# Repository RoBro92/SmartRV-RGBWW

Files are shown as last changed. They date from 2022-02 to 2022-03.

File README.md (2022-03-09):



# SmartRV RGBWW Controller
**A ESP32 based RGBWW controller**

All feature requests are tracked in the GitHub issue tracker. 
[Feature Requests](https://github.com/RoBro92/feature-requests/issues)

This RGBWW control board has been designed to allow smart control of an attached LED strip. It supports 5 seperate channels that are switched via N Channel Mosfets, this is sutiable for the majority of LV LED devices. It is designed to integrate with a home automation system such as Home Assistant, though can operate standalone via an access point.

The module has been kept as compact as possible and allows for a direct connection to 12v or 24v vehicle systems. 

**If you want to support the development you can purchase this board as a DIY kit or assembled from my Ko-Fi Shop [SmartRV Shop](https://ko-fi.com/smartrv/shop)**

# **v0.1**
This is the pre-production initial design files with planned features and initial designs. Design is as far untested.

# **New This Release**

- [x] Upload full Kicad files

# **Current Features**
- [x] ESP32 Microcontroller
- [x] Serperate 5 channel LED control 1a per channel
- [x] Reverse voltage protection
- [x] FTDI programmer pinout
- [x] 12v input

# **Upcoming Changes**
- [ ] On board programming
- [ ] Bluetooth connection to hub

# **Images**
<table>
  <tr>
    <td>3D Model</td>
     <td>PCB Schematic</td>
  </tr>
  <tr>
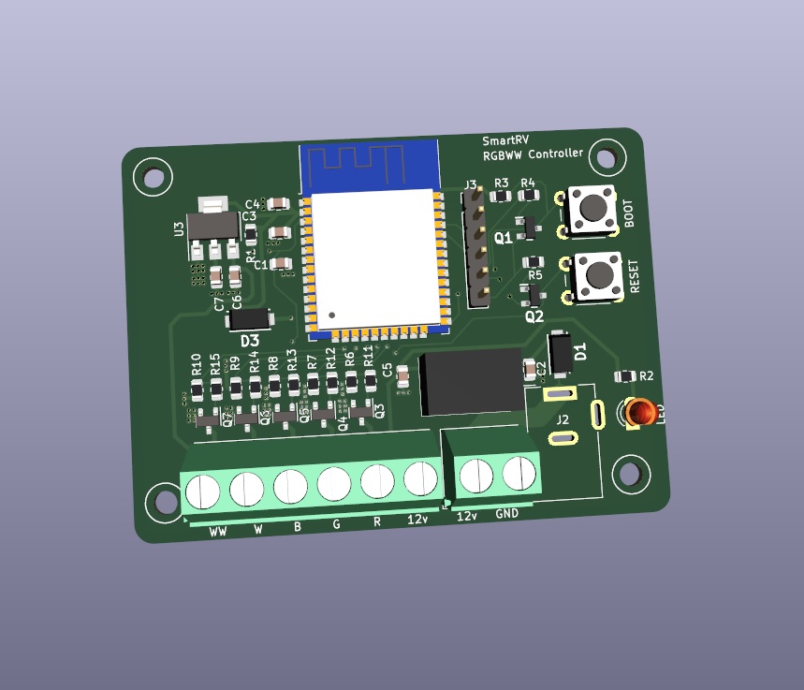
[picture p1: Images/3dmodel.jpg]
    <td></td>
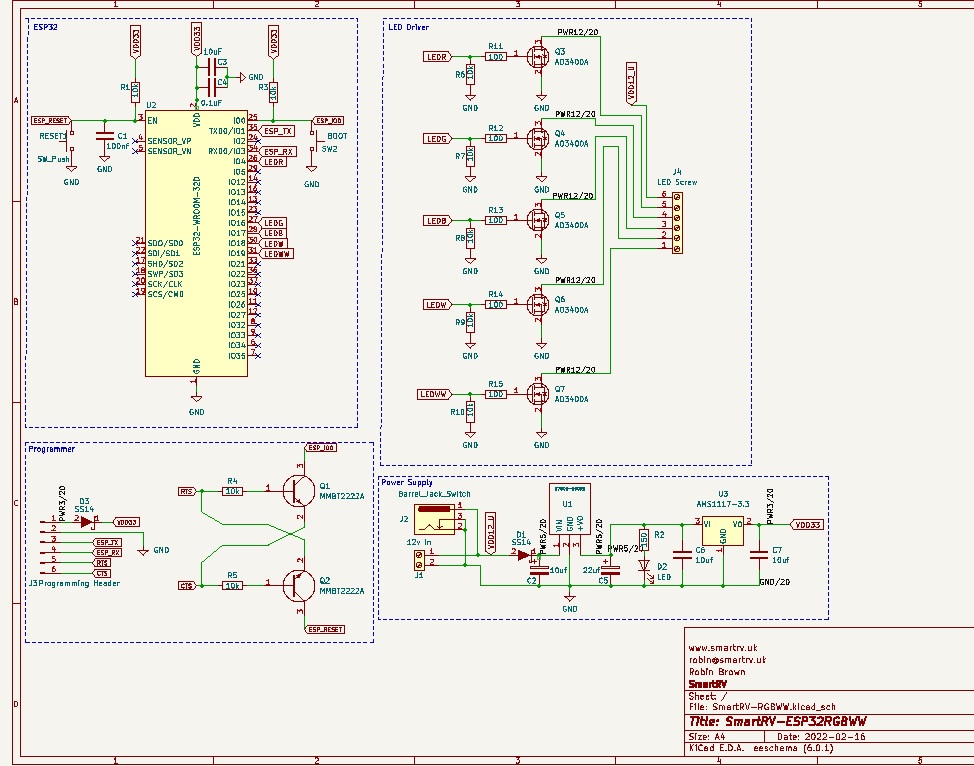
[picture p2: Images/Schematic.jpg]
    <td></td>
  </tr>
 </table>
 
 <table>
  <tr>
    <td>PCB Layout</td>
  </tr>
  <tr>
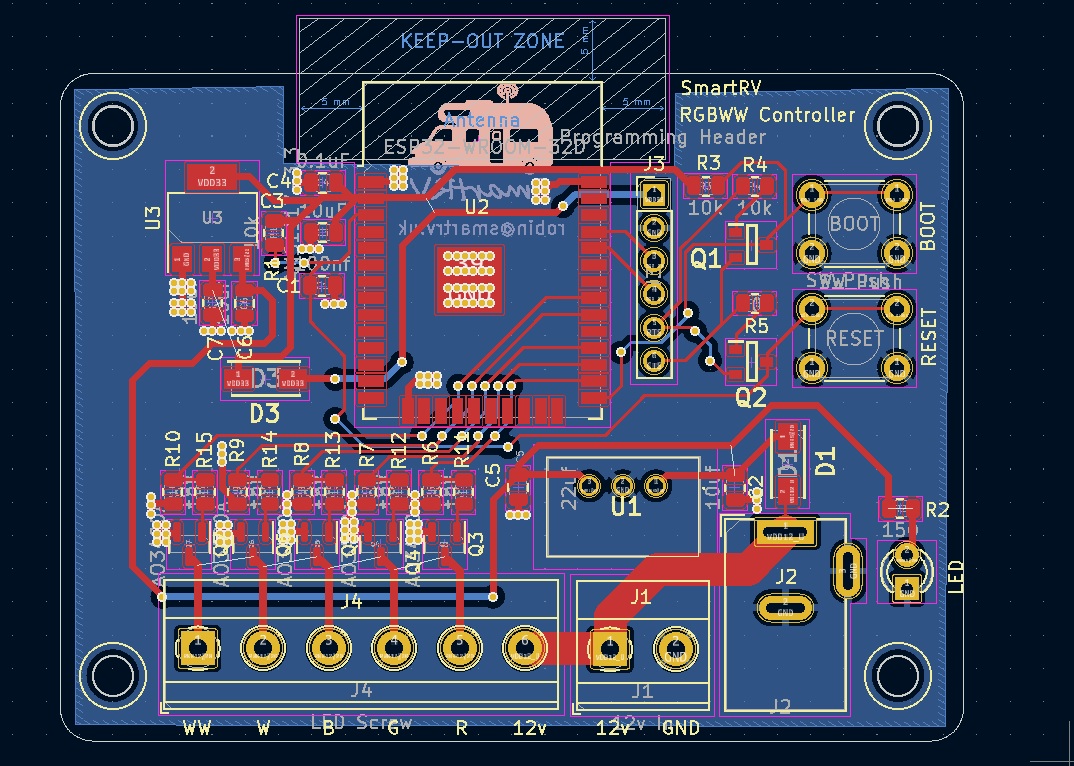
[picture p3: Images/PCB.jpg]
    <td></td>
  </tr>
 </table>

# **WARNING**
This board does not have any fuse protection as such this must be provided externally.# SmartRV-RGBWW

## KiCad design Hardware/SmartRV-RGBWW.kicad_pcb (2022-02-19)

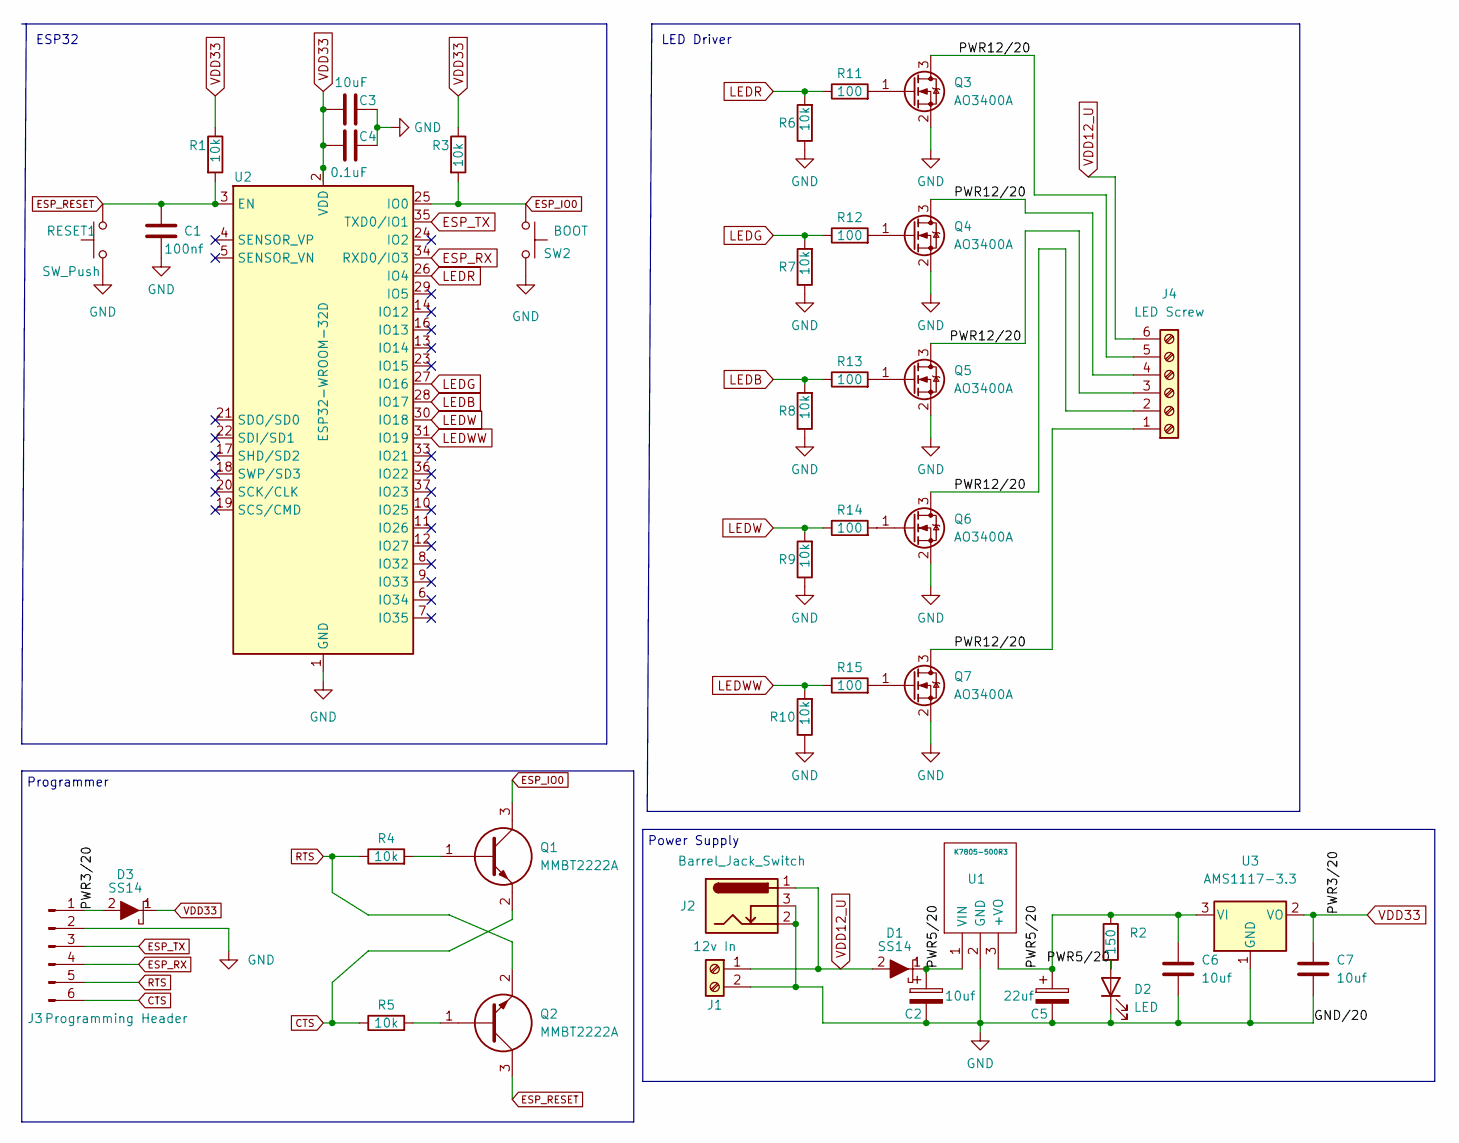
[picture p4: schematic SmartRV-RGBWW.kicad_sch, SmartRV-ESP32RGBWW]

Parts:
C1: 100nf; C_0805_2012Metric
C2, C6, C7: 10uf; C_0805_2012Metric
C3: 10uF; C_0805_2012Metric
C4: 0.1uF; C_0805_2012Metric
C5: 22uf; C_0805_2012Metric
D1, D3: SS14; DIOM5126X250N; Manufacturer_Part_Number SS14; Mouser Part Number 821-SS14
D2: LED; LED_D3.0mm; Fwd Voltage 2-2.2
J1: 12v In; TerminalBlock_Phoenix_MKDS-1,5-2_1x02_P5.00mm_Horizontal
J2: Barrel_Jack_Switch; BarrelJack_Wuerth_6941xx301002
J3: Programming Header; PinHeader_1x06_P2.54mm_Vertical
J4: LED Screw; TerminalBlock_Phoenix_MKDS-1,5-6_1x06_P5.00mm_Horizontal
Q1, Q2: MMBT2222A; SOT95P240X120-3N; Manufacturer_Part_Number MMBT2222A; Mouser Part Number 512-MMBT2222A
Q3, Q4, Q5, Q6, Q7: AO3400A; SOT-23
R1, R3, R4, R5, R6, R7, R8, R9, R10: 10k; R_0805_2012Metric
R2: 150; R_0805_2012Metric
R11, R12, R13, R14, R15: 100; R_0805_2012Metric
RESET1: SW_Push; SW_PUSH_6mm
SW2: BOOT; SW_PUSH_6mm
U1: K7805-500R3; K7805500R3; Manufacturer_Part_Number K7805-500R3
U2: ESP32-WROOM-32D; ESP32-WROOM-32
U3: AMS1117-3.3; SOT-223-3_TabPin2

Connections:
/PWR5/20: C2.1, C5.1, C6.1, D1.1, D2.2 (A), R2.1, R2.2, U1.1 (VIN), U1.3 (+VO), U3.3 (VI)
/PWR12/20: J4.1, J4.2, J4.3, J4.4, J4.5, Q3.3 (D), Q4.3 (D), Q5.3 (D), Q6.3 (D), Q7.3 (D)
CTS: J3.6, Q1.2, R5.1
ESP_IO0: Q1.3, R3.2, SW2.1, U2.25 (IO0); also elsewhere on the board
ESP_RESET: C1.2, Q2.3, R1.2, RESET1.2, U2.3 (EN); also elsewhere on the board
ESP_RX: J3.4, U2.34 (RXD0/IO3)
ESP_TX: J3.3, U2.35 (TXD0/IO1)
GND: C1.1, C2.2, C3.2, C4.2, C5.2, C6.2, C7.2, D2.1 (K), J1.2, J2.2, J2.3, J3.2, Q3.2 (S), Q4.2 (S), Q5.2 (S), Q6.2 (S), Q7.2 (S), R6.1, R7.1, R8.1, R9.1, R10.1, RESET1.1, SW2.2, U1.2 (GND), U2.1 (GND), U2.15 (GND), U2.38 (GND), U2.39 (GND), U3.1 (GND); also elsewhere on the board
LEDB: R8.2, R13.1, U2.28 (IO17)
LEDG: R7.2, R12.1, U2.27 (IO16)
LEDR: R6.2, R11.1, U2.26 (IO4)
LEDW: R9.2, R14.1, U2.30 (IO18)
LEDWW: R10.2, R15.1, U2.31 (IO19)
unnamed: Q1.1, R4.2
unnamed: Q2.1, R5.2
unnamed: Q3.1 (G), R11.2
unnamed: Q4.1 (G), R12.2
unnamed: Q5.1 (G), R13.2
unnamed: Q6.1 (G), R14.2
unnamed: Q7.1 (G), R15.2
RTS: J3.5, Q2.2, R4.1
VDD12_U: D1.2, J1.1, J2.1, J4.6
VDD33: C3.1, C4.1, C7.1, D3.1, D3.2, J3.1, R1.1, R3.1, U2.2 (VDD), U3.2 (VO)

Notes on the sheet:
ESP32
Power Supply
Programmer
LED Driver

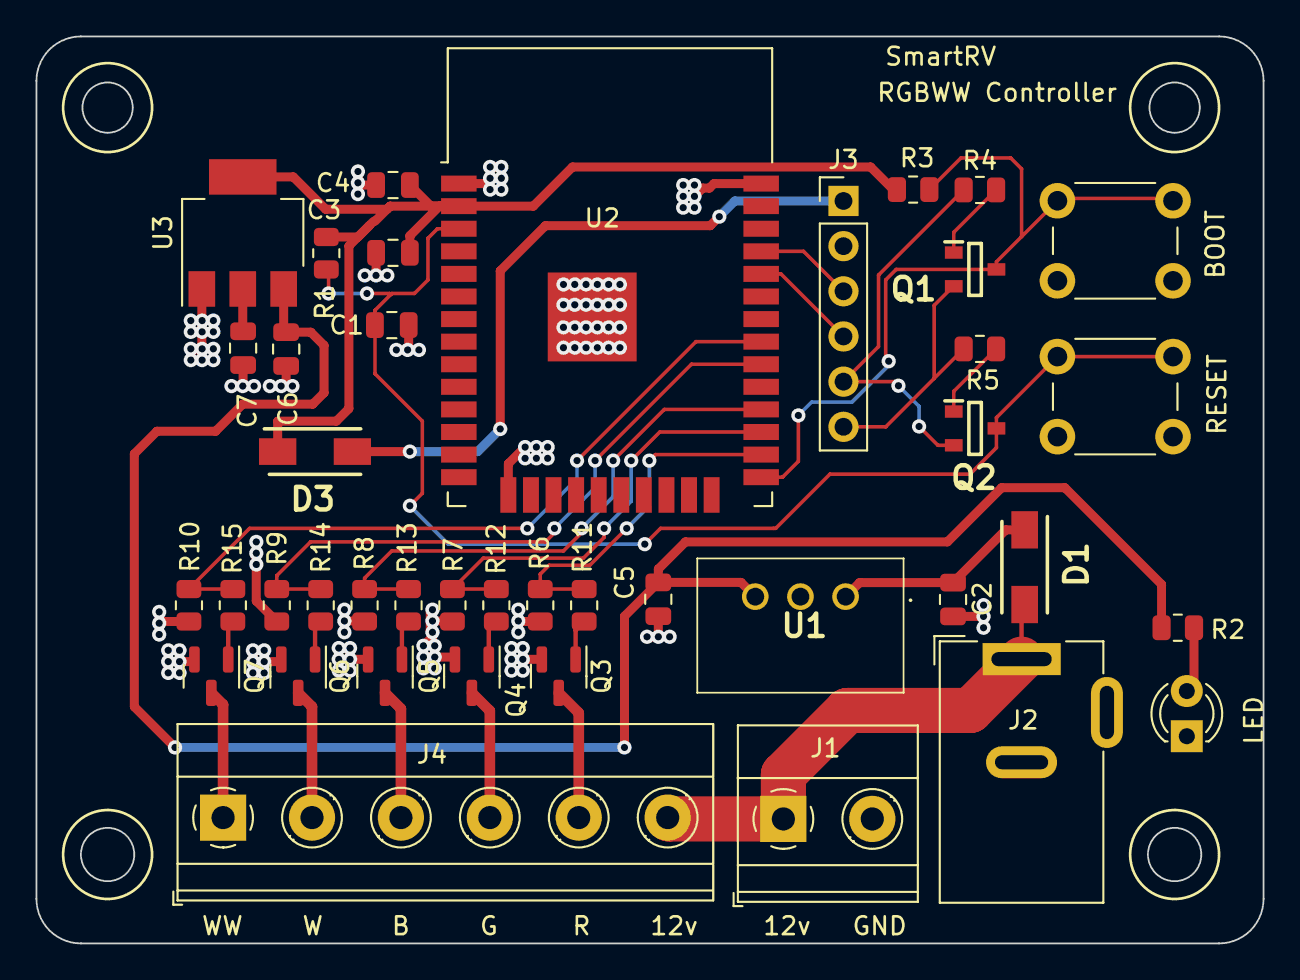
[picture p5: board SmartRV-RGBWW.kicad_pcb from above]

Board: 2 copper layers, 69.0 x 51.0 mm, 41 parts (0 on the bottom side), 23 nets.

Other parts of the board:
BOOT: SW_Push; SW_PUSH_6mm
RESET: SW_Push; SW_PUSH_6mm

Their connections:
ESP_IO0: BOOT.1; also elsewhere on the board
ESP_RESET: RESET.2; also elsewhere on the board
GND: BOOT.2, RESET.1; also elsewhere on the board

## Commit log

2022-02-19 Added Image files and PCB/Schematic
    [SmartRV-RGBWW.kicad_pcb, SmartRV-RGBWW.kicad_sch]
2022-02-19 added Schematic and PCB files
    [SmartRV-RGBWW.kicad_pcb, SmartRV-RGBWW.kicad_sch]
